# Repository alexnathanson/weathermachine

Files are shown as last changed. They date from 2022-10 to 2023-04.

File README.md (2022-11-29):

# weathermachine

All the code for controlling the system from a centralized computer/ server is in main

To run:

`python main`

To do:

smooth numbers over time (change based on user input - currently hard coded)
light output is an array for some reason...
export test settings?
add gauges
shift to REACT
refactor

Troubleshooting:

If you get a serial error, make sure to close all Arduino windows to ensure that only Python is communicating via Serial

clean data is defined here as data with 1 single row of headers.
it does not necessarily mean there aren't problems in the data

HEADERS:
Date
HH:MM
Datasource
Dry Bulb Temperature {C}
Dew Point Temperature {C}
Relative Humidity {%}
Atmospheric Pressure {Pa}
Extraterrestrial Horizontal Radiation {Wh/m2}
Extraterrestrial Direct Normal Radiation {Wh/m2}
Horizontal Infrared Radiation Intensity from Sky {Wh/m2}
Global Horizontal Radiation {Wh/m2}
Direct Normal Radiation {Wh/m2}
Diffuse Horizontal Radiation {Wh/m2}
Global Horizontal Illuminance {lux}
Direct Normal Illuminance {lux}
Diffuse Horizontal Illuminance {lux}
Zenith Luminance {Cd/m2}
Wind Direction {deg}
Wind Speed {m/s}
Total Sky Cover {.1}
Opaque Sky Cover {.1}
Visibility {km}
Ceiling Height {m}
Present Weather Observation
Present Weather Codes
Precipitable Water {mm}
Aerosol Optical Depth {.001}
Snow Depth {cm}
Days Since Last Snow
Albedo {.01}
Liquid Precipitation Depth {mm}
Liquid Precipitation Quantity {hr}

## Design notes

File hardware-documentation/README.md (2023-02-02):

# Hardware

## LED panel

4 total

https://www.mars-hydro.com/ts-3000-led-grow-light

## LED Power Supply

1 per LED panel

https://www.meanwell.com/webapp/product/search.aspx?prod=ELG-240

## LED Light PWM Driver

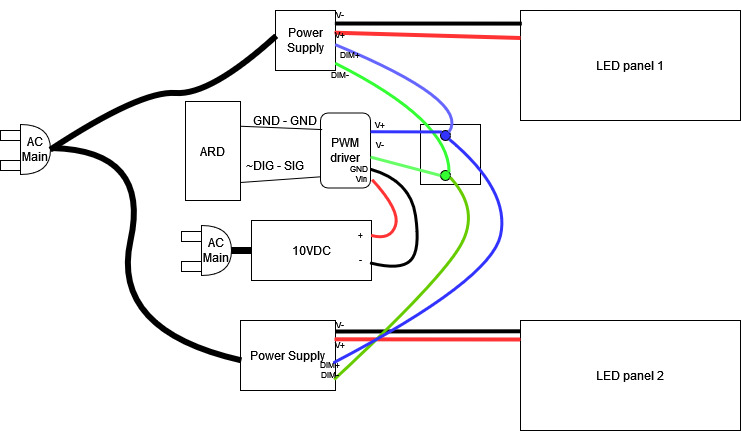
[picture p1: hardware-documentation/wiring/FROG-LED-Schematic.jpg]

IRF520 MOSFET Driver Module

Max:<br>
24VDC<br>
5A (>1A requires heatsink)

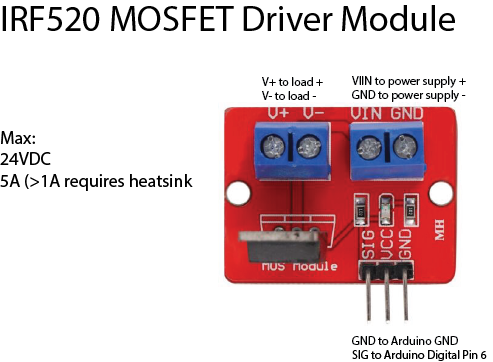
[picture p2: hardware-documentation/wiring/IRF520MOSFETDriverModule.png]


### Purchase Link

* 10VDC Power supply w/ barrel jack breakout https://www.amazon.com/gp/product/B09HT1BB2C/ref=ox_sc_act_title_1?smid=A362H7KPT65UPW&psc=1
* Mosfet driver board:
https://www.amazon.com/dp/B09TFFNH32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

## Pump motor driver

7-30VDC
10A (15A peak)

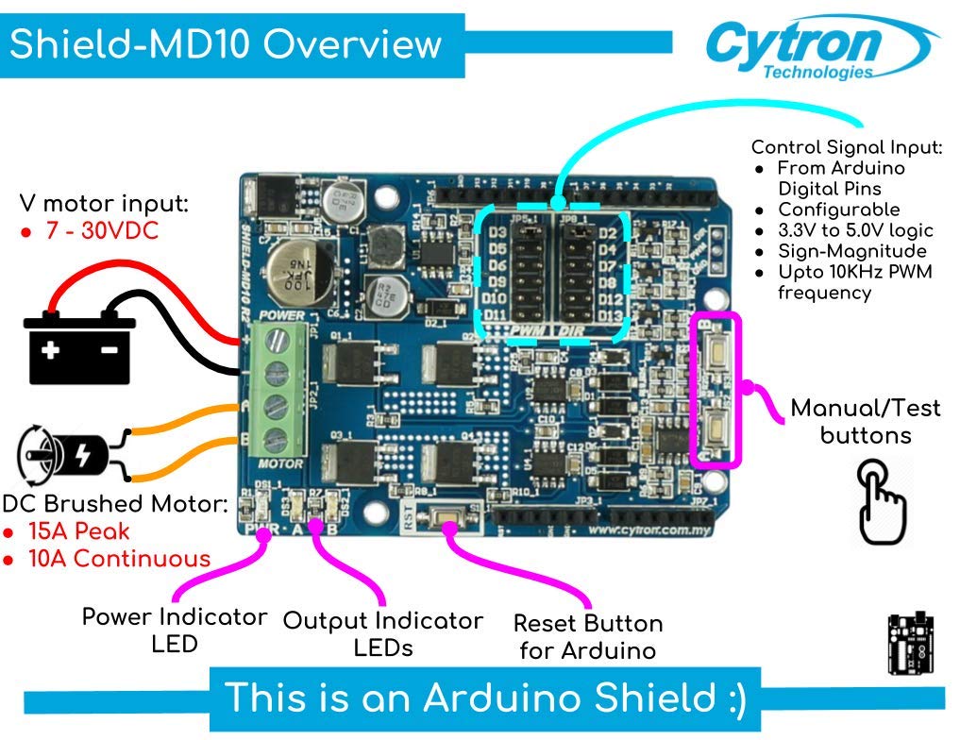
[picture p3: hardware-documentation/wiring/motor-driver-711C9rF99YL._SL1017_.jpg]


### Purchase Link

* https://www.amazon.com/Cytron-Bi-directional-Driver-Shield-Arduino/dp/B01M3WQWRK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

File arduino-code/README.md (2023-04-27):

# Arduino I2C network

This system is composed of 5 Arduinos and a computer that acts as the test runner (TR).

The test runner is a Python program. It sends commands via Serial. 1 Arduino receives this serial data and passes it on to all the other Arduinos that run individual subsystems via I2C. The system is intended to be modular, to enable the system to run with any amount of subsystems connected and so development work can happen more easily.

Some of the individual subsystems have sensors. In some cases these sensors are just used for control feedback to maintain a certain output level, but in some cases sensor data may need to be logged. For this reason, communication in the system is bidirectional. All subsystem Arduinos can pass data back to the TR via sending it over I2C to the broadcaster Arduino, which converts it in to Serial to send to the TR.

The TR determines what commands to send to the subsystems based on user defined test parameters (see the main README.md file for more info). The data originates from an EPW file. In order to simplify comunication and computational load on the Arduinos, the least amount and smallest dimension of data is sent to the Arduinos as possible. Some of subsystem data requires preprocessing that happens on the TR either before the test or on the fly at runtime. In some cases, the Arduino does handle a small amount of preprocessing.

The only piece of code necessary is the serial-to-i2c-bidirectional-subsystem-control.ino script. Change the subsystem variable to the correct number and the Arduino will automatically parse messages and run the correct subsystem. (Currently, the only subsystem code included is for the lights and humidity systems.)

## Installation of serial-to-i2c-bidirectional-subsystem-control.ino

### Software

Make sure to change the I2C address based on the list of subsystem addresses below.

Install Arduino Json https://arduinojson.org/v6/doc/installation/

### Wiring

All Arduinos are connected together via pins GND, A4, and A5. Note that if Arduinos share a power supply with a common ground, the GND pin connection isn't necessary.

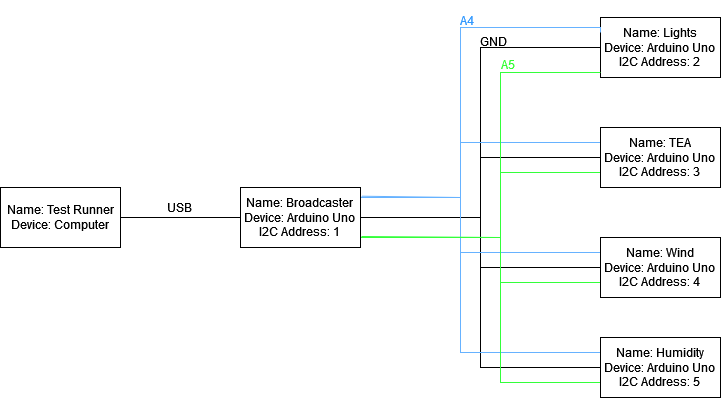
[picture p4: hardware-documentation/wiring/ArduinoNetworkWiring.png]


### Adddresses

 * BROADCASTER : 1
 * LIGHTS : 2
 * TEA : 3
 * WIND : 4
 * HUMIDITY : 5

## Subsystems

### Lights

The lights are controlled via PWM from the Arduino. There are no sensors. Preprocessing of the light data happens at the test runner and only 1 0-255 value is passed to the Arduino.

* Original data sources: Global Horizontal Radiation {Wh/m2}, Diffuse Horizontal Radiation {Wh/m2}, and Direct Normal Radiation {Wh/m2} is reduced down to 1 value based on surface orientation.
* Preprocessing on TS: Surface orientation value is scaled to the 0-255 range.
* Output from TS to Arduino: integer 0-255
* Output from Arduino to light circuit: PWM

### TEA

* Original data sources: Temperature TBD
* Preprocessing on TS: TBD
* Output from TS to Arduino: 1 temperature value
* Output from Arduino to circuit: 2 values (intensity and direction)

### Humidity

* Original data sources: humidity value TBD
* Preprocessing on TS: likely none
* Output from TS to Arduino: 1 value TBD
* Output from Arduino to circuit: TBD wind velocity and temperature

### Wind

* Original data sources: Wind velocity and direction TBD
* Preprocessing on TS: TBD - preprocessing of wind velocity + direction to get 1 value will be required
* Output from TS to Arduino: 1 value TBD
* Output from Arduino to circuit: TBD wind velocity and temperature

## Communication Protocol & Serial String Structure

### From TS to Broadcaster via Serial
The TS sends all data to the Arduino network as a JSON dictionary in the following format. Regardless of what subsystem info is include, all data is broadcast to the entire network. This can be changed in the future if it leads to problems.

`{ lights : [int 0-255]}`

or for multiple values: 

`{ lights : [int 0-255], tea: [int 0-255],hum:[int 0-255],wind:[int 0-255]}`

### Broadcaster On receiving Serial:

1) parse JSON
2) break up JSON data by subsystem
3) broadcast all data to all devices

### Broadcaster on receiving I2C:

1) pass incoming data to Serial

### Subsystems on receiving Serial:

1) send to Broadcaster via 12C

### Subsystems on receiving I2C:

1) parse incoming JSON data
2) check if data is intended for the particular subsystem
3) if yes, run run system functions

### From Arduino to TS

Because exact sensor data that would get sent from subsystems to TS for archiving isn't available yet, that specific format isn't finalized, but it will probably follow a similar JSON format as above, except messages would be seperated out as individual subsystems like the below theoretical example with 3 different temperature sensors. As with communication in the other direction, it is best to reduce the dimension of data if possible. So in this example, unless you need to archive all 3 pieces of data it would be best to just send an average.

`{ tea: {temp1: [int 0-255], temp2: [int 0-255], temp3: [int 0-255]}`

## Troubleshooting

### Network status

In the Arduino IDE console, type "info" and the Arduino will respond with 
* its own I2C address
* a list of all the I2C devices and their addresses that it can detect
* the total number of I2C devices it can detect

In the Arduino IDE console, type "test" and the Arduino will send a properly formatted I2C message with 0 values

### Message Content

In the Arduino IDE, open a console and any incoming messages from I2C should print out as they come in.

## Adding Subsystem Specific Code

## Future Work

It might be best to have 1 library that encompasses all network functions and subsystem functions so that each Arduino can have identical software running.

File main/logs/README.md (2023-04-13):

# Logs

## Naming convention

scriptYEAR-MONTH-DAY-HOUR-MINUTE.log

Log file names starting with 'tester' are run from the arduinoTester script.
Log file names starting with 'runner' are run from the experiment runner script.

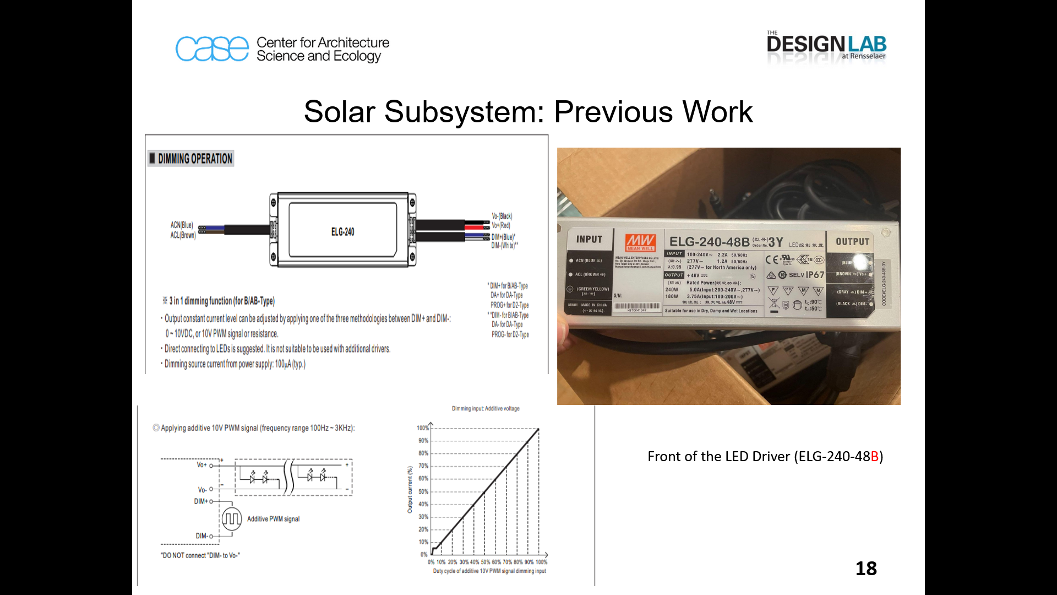
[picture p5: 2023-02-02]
hardware-documentation/Screenshot (737).png

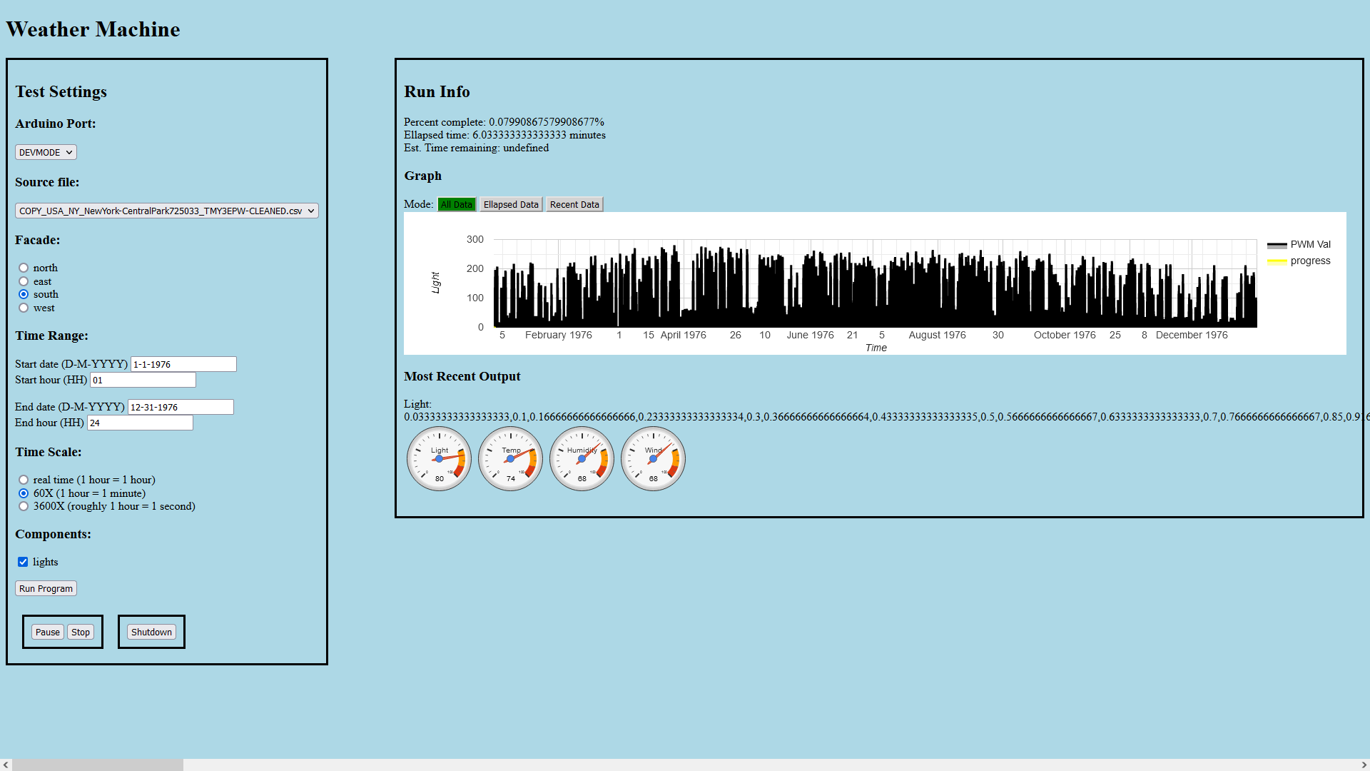
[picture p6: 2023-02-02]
hardware-documentation/interface-screenshot-January30-2023.png

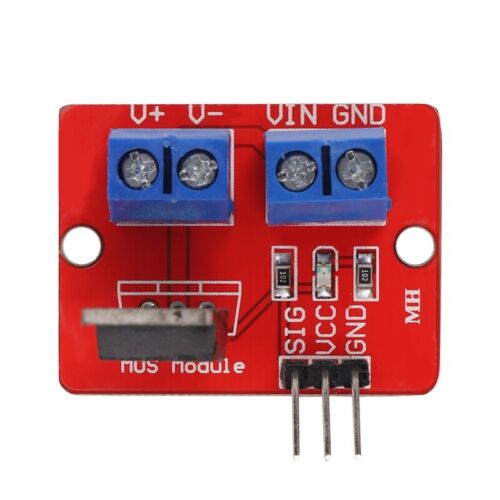
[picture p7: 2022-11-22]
hardware-documentation/IRF520-MOS-PWM.jpg

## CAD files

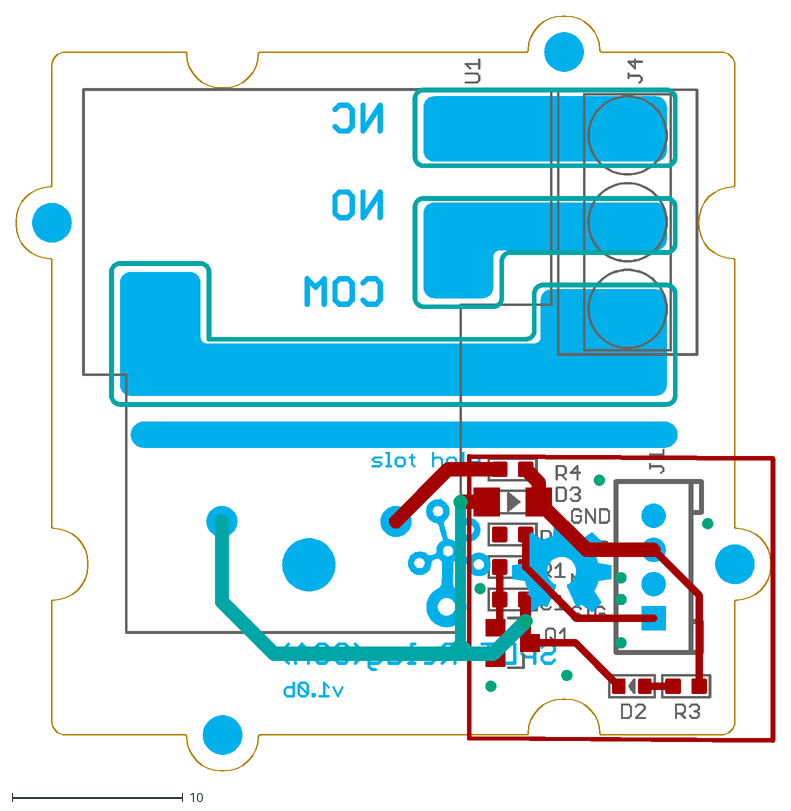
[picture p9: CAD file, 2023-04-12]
integration-and-installation/Grove_-_SPDT_Relay(30A)_Eagle_File/Grove - SPDT Relay(30A) Eagle File/Grove ¿C SPDT Relay(30A) v1.0.dxf
44.5 x 44.2

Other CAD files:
integration-and-installation/ArduinoUno.dxf

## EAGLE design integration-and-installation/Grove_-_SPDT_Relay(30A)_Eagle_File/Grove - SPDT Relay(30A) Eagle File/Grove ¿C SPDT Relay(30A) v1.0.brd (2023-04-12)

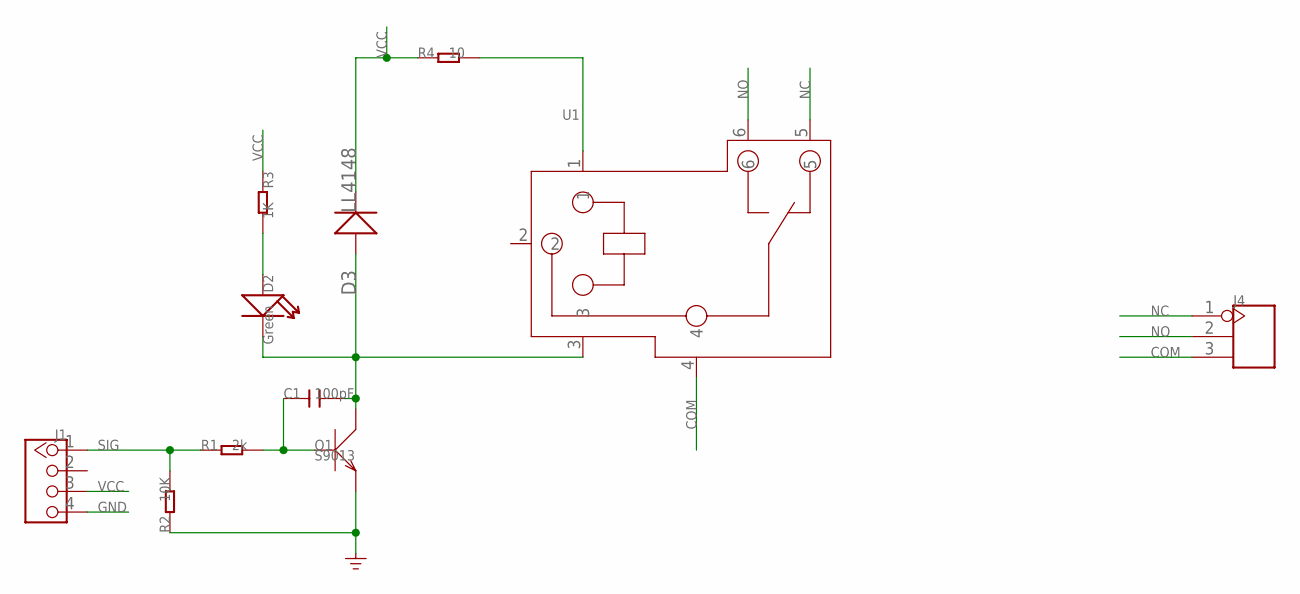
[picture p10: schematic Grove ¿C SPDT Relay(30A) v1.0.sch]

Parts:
C1: 100pF; C0603
D2: Green; LED-0603
D3: LL4148; DO-35-SMD
J1: TWIG-4P-2.0-2.0; 4P-2.0
J4: SCREW-TERMINAL-3P'5.08'; 3P-5.08
Q1: S9013; SOT23
R1: 2k; R0603
R2: 10K; R0603
R3: 1K; R0603
R4: 10; R0603
U1: RELAY-SLA-05VDC-SL-C; 6P-19.8H

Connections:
COM: J4.3, U1.4
GND: J1.4, Q1.2 (E), R2.1
unnamed: C1.1, Q1.1 (B), R1.2
unnamed: D2.+, R3.2
unnamed: C1.2, D2.-, D3.A (+), Q1.3 (C), U1.3
unnamed: R4.2, U1.1
NC: J4.1, U1.5
NO: J4.2, U1.6
SIG: J1.1, R1.1, R2.2
VCC: D3.C (-), J1.3, R3.1, R4.1

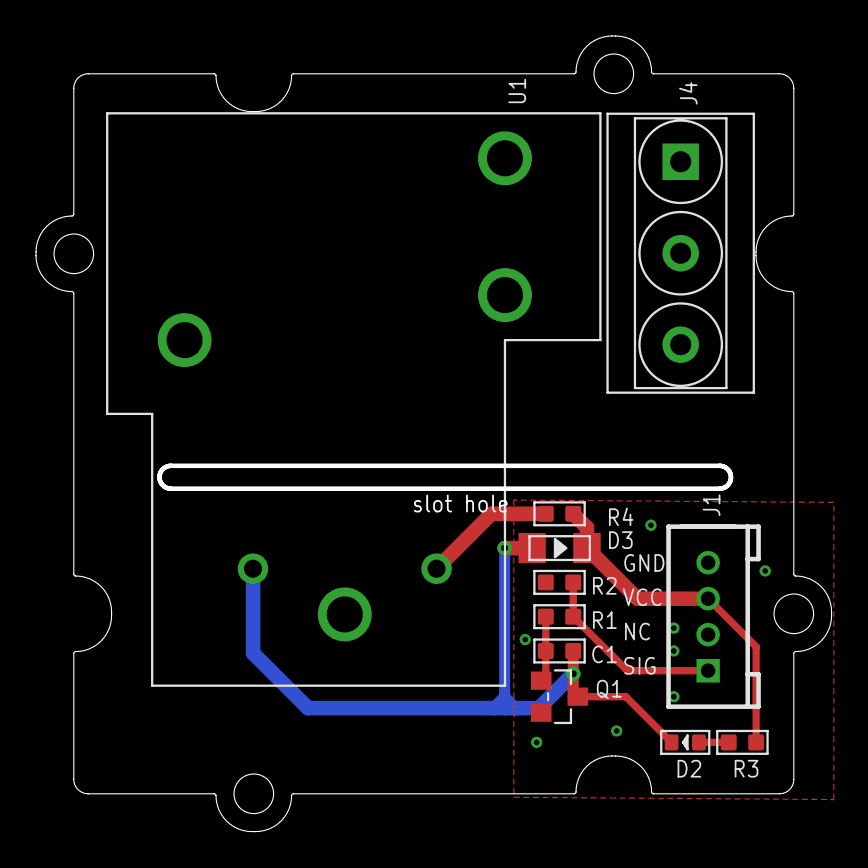
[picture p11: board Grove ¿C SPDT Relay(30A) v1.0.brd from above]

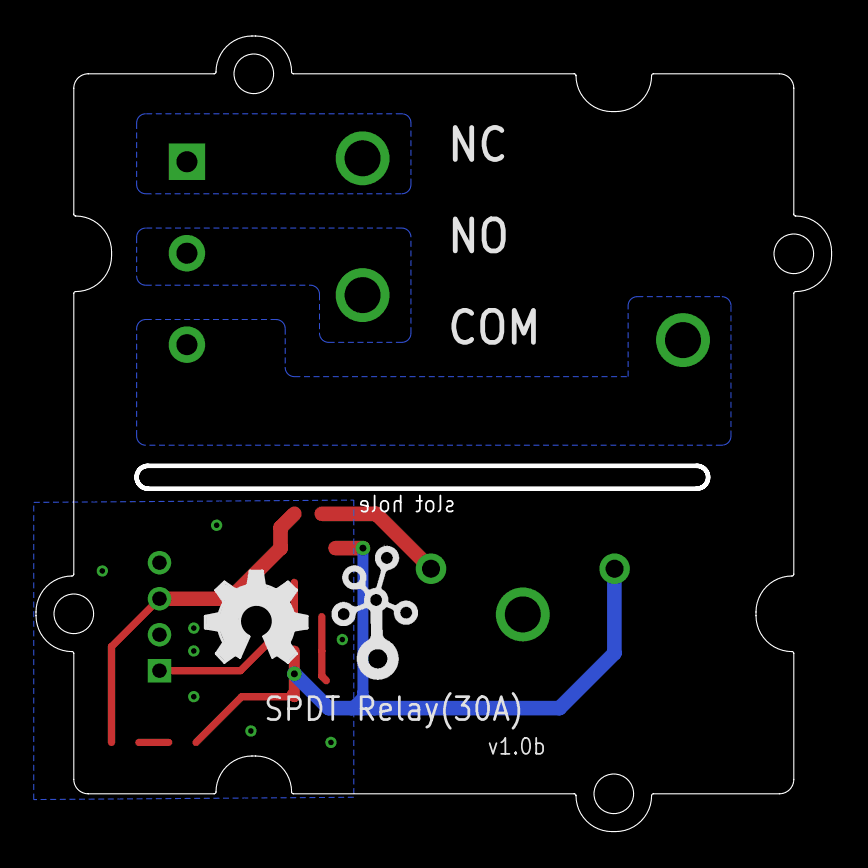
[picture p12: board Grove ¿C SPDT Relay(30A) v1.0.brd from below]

Board: 2 copper layers, 44.2 x 44.2 mm, 14 parts (2 on the bottom side), 10 nets.

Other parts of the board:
U$3: 2X2U-DIM-W/-DRILL
U$4: OSHW_FILLX200_NOTEXT
U$5: TWIGLOGO

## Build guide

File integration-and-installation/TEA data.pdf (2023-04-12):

Arduino | I/O | Analog/digital | Auto/Manual
Temp Sensor 1 | input | analog | Automatic
Temp Sensor 2 | input | analog | Automatic
Temp Sensor 3 | input | analog | Automatic
Temp Sensor 4 | input | analog | Automatic
TEM Power | out | PWM 0-255 mapped to 0-100 | Adjustments should eventually be automatic after manual input of a desired temperature, currently we are setting the power manually
4. A closed feedback loop should be utilized to maximize efficiency of the TEM. The input of the system will be a desired temperature. The controller will likely be a constant gain value that we have not yet determined. This will determine the power of the TEM, or the process. Then, the output of the process will be sent back into the system by the sensors. The error will be calculated, then this will again determine the new power of the system.

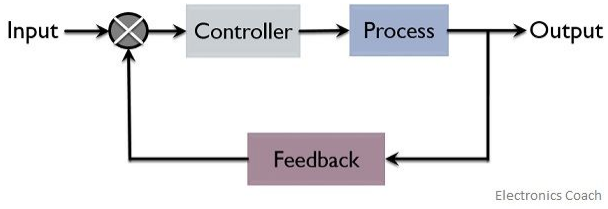
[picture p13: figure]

6. After increasing the desired power of the TEM by 10%, it took about 4 minutes for the temperature to stabilize. This usually results in a temperature increase/decrease of about 1.5 degrees Celsius. So far this is all the testing we have done, more tests will need to be obtained to get more useful and accurate data.

Data sheets

TEA:
https://lairdthermal.com/products/thermoelectric-cooler-assemblies/peltier-air-conditioners/AA-4 80-24-44 (https://lairdthermal.com/products/thermoelectric-cooler-assemblies/peltier-air-conditioners/AA-480-24-44)

H-Bridge:
https://www.pololu.com/product/2994

Power Supply (SE-1000-24): https://www.meanwell.com/productPdf.aspx?i=475

Temperature Sensors:
https://www.te.com/usa-en/product-CAT-HSA0001.html

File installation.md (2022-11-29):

# Installation

## Install Python3

https://www.python.org/downloads/

## Set up virtual environment

Create a virtual environment

https://docs.python.org/3/library/venv.html

## install requirements from requirements.txt

`pip install -r requirements.txt`

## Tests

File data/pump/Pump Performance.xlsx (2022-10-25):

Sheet: 100ft Tubing
Voltage (V) | Current (A) | Power (W) | Flow Rate (LPM)
1.999 | 2.073 | 4.14 | 1.07
2.999 | 3.391 | 10.17 | 1.75
3.999 | 4.225 | 16.90 | 2.33
4.998 | 5.315 | 26.56 | 2.87
5.997 | 6.282 | 37.67 | 3.37
6.997 | 7.183 | 50.26 | 3.75
7.997 | 7.788 | 62.28 | 4.09

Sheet: 200ft Tubing
Voltage (V) | Current (A) | Power (W) | Flow Rate (LPM)
1.999 | 2.598 | 5.19 | 0.83
2.999 | 3.703 | 11.11 | 1.44
3.999 | 4.501 | 18.00 | 1.86
4.998 | 5.551 | 27.74 | 2.22
5.997 | 7.321 | 43.90 | 2.62

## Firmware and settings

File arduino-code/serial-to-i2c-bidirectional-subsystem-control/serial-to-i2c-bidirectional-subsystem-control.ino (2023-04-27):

/*This code manages communications between and control of all subsystems.
 * This is the only Arduino code necessary. Change the subsystem variable to the correct value
 * and it will automatically parse messages and run the correct code for the specified subsystem
 * 
 *For more info see the README at:
 *https://github.com/alexnathanson/weathermachine/tree/main/arduino-code 
 */

/*
 * I2C Addresses:
 * BROADCASTER : 1
 * LIGHTS : 2
 * TEA : 3
 * WIND : 4
 * HUMIDITY : 5
 */

#include <Wire.h>
#include <ArduinoJson.h>

byte i2cDevices[128];
int nDevices = 0;

//value should correlate to i2c addressses listed above
const int subsystem = 5;

/*** LIGHT VARIABLES ***/
const int ledPin = 9;
int ledBrightness = 0;

/*** TEA VARIABLES ***/

/*** WIND VARIABLES ***/

/*** HUMIDITY VARIABLES ****/
float RHValue = 50.0;     // Defining the humidity set point in percentage (This value will be imported from weather file)
float PlusOrMinus = 5.0;  // Defining the lower and upper set point for humidity (This value can be changed as per user...)
                          // (...settings. Below lower set point, humidifier will operate and above upper set point, dehumidifier will operate)
const int VP = A0;                    // Defining the pin for analog input through RH sensor
const int HumPin = 4, DeHumPin = 10;  // Defining the pins for digital output to control humidifier and dehumidifier operation

void setup() {
  //initialize array as all 0
  setupDeviceList();

  // Initialize I2C bus
  Wire.begin(subsystem); 
  Wire.setWireTimeout(3000, false);
  Wire.onReceive(receiveEvent); // register event
  //Wire.onRequest(requestEvent); //register event
  
  Serial.begin(9600); // Initialize serial communication

  /*** HUMIDITY VARIABLES ****/
  if(subsystem == 2){
    //lights
    pinMode(ledPin, OUTPUT);
  } else if(subsystem == 3){
    //TEA
  } else if(subsystem == 4){
    //Wind
  } else if(subsystem == 5){
    //humidity
    pinMode(HumPin, OUTPUT);            // Defining the pin for digital output to control the humidifier operation
    pinMode(DeHumPin, OUTPUT);          // Defining the pin for digital output to control the dehumidifier operation
  }
}

void loop() {
  // Read serial input and send it over I2C
  if (Serial.available()) {
    String message = Serial.readStringUntil('\n'); // Read serial message until newline character

    //respond to the info request with your own info
    if (message == "info"){
      Serial.println("***INFO***");
      Serial.println("My address is " + String(subsystem));
      scannerI2C();
    } else if (message == "test"){//run a test
      
      String testJSON = "{\"lights\":254,\"tea\":3,\"hum\":98,\"wind\":176}";
      parseJSON(testJSON);
      delay(3000);
      testJSON = "{\"lights\":0,\"tea\":0,\"hum\":0,\"wind\":0}";
      parseJSON(testJSON);

    } else {
      //Serial.println(message);

      //if broadcaster, parse serial data and broadcast it
      if(subsystem == 1){
        parseJSON(message);
      } else {
        broadcastI2C(message);//
      }
      
    }
  }
  
  if(subsystem == 2){
    lightLoop();
  } else if(subsystem == 3){
    teaLoop();
  } else if(subsystem == 4){
    windLoop();
  }else if(subsystem == 5){
    humidityLoop();
  }
}

void lightLoop(){
  analogWrite(ledPin, ledBrightness);
}

void teaLoop(){
  
}

void windLoop(){
  
}

/* Code for humidity subsystem*/
void humidityLoop(){
  int val, count = 40;
  float RH, avg = 0.0, volt;
  float MinLim, MaxLim;
  for (int i = 0; i < count; i++){
    val = analogRead(VP);             // Reading the voltage analog input signal (0-5V) from the RH sensor
    volt = val * 5000.0/1023.0;       // Converting the bit value of voltage analog signal to mV 
    RH = -1.92 * pow(10,-9)*pow(volt,3) + 1.44 * pow(10,-5) * pow(volt,2) + 3.4 * pow(10,-3) * volt - 12.4;
                                      // Manufacturer specified equation to convert voltage input in mV to RH in percentage
    avg += RH;                        // Adding all the RH readings to average over a period of 20s
    delay(500);                       // Adding a delay of 0.5s between recording sensor readings
  }
  avg /= count;                       // Obtaining the average RH value for the period of 20s
  if (RHValue - PlusOrMinus < 0)
    MinLim = 0;
  else
    MinLim = RHValue - PlusOrMinus;
                                      // Logic section to set the lower set point for relative humidity
  if (RHValue + PlusOrMinus > 100)
    MaxLim = 100;
  else
    MaxLim = RHValue + PlusOrMinus;
                                      // Logic section to set the lower set point for relative humidity
  if (avg <= MinLim)
    digitalWrite(HumPin, HIGH);       // Digital signal to operate the humidifier through a relay module
  else
    digitalWrite(HumPin, LOW);        // Digital signal to stop the operation of the humidifier through a relay module

  if (avg >= MaxLim)
    digitalWrite(DeHumPin, HIGH);     // Digital signal to operate the dehumidifier by powering the fuse and capacitor in ...
                                      // ... its power module
  else
    digitalWrite(DeHumPin, LOW);      // Digital signal to stop the operation of the dehumidifier by cutting the power to ...
                                      // ... the fuse and capacitor in its power module
}

// function that executes whenever data is received from I2C broadcaster
// this function is registered as an event, see setup()
void receiveEvent(int howMany) {
  String incomingI2C = "";//initialize string
  
  while (1 <= Wire.available()) { // loop through all bytes
    char c = Wire.read(); // receive byte as a character
    incomingI2C += c;
    //Serial.print(c);         // print the character
  }
  

  //if not the broadcaster, parse the data to do something with it
  if(subsystem != 1){
      parseJSON(incomingI2C);
      // if a subsystem, you can use this for troubleshooting in the IDE console
      //Serial.println(incomingI2C);
  } else {
    // if broadcaster, this just passes it on to the test runner
    Serial.println(incomingI2C);
  }
  //int x = Wire.read();    // receive byte as an integer
}

//this is only necessary if the Broadcaster hasn't specified an address and needs to request info
/*void requestEvent() {
  Wire.write("hello "); // respond with message of 6 bytes
}*/

void setLights(int brightness){
  Serial.print("Running Lights: ");
  Serial.println(brightness);
  ledBrightness = brightness;
  
  /*if (brightness == 0){
    digitalWrite(ledPin, LOW);
  } else {
    digitalWrite(ledPin, HIGH);
  }*/
}

void setTea(int temp){
  Serial.print("Running TEA: ");
  Serial.println(temp);
  digitalWrite(ledPin, temp);
}

void setHumidity(float humidity){
  Serial.print("Running Humidity: ");
  Serial.println(humidity);
  digitalWrite(ledPin, humidity);

  RHValue = humidity;     // Defining the humidity set point in percentage converted to float
}

void setWind(int wind){
  Serial.print("Running Wind: ");
  Serial.println(wind);
  digitalWrite(ledPin, wind);
}


void setupDeviceList(){
  for (byte d = 0; d < 128; ++d) {
    i2cDevices[d]=0;  
  }  
}

//scan for all connected i2c devices
void scannerI2C(){
  nDevices = 0;
  
  for (byte address = 1; address < 127; ++address) {
    // The i2c_scanner uses the return value of the Wire.endTransmission
    //to see if a device did acknowledge to the address.
    Wire.beginTransmission(address);
    byte error = Wire.endTransmission();

    if (error == 0) {
      Serial.print("I2C device found at address 0x");
      Serial.println(address, HEX);
      i2cDevices[nDevices]=address;
      nDevices = ++nDevices;
    } else if (error == 4) {
      Serial.print("Unknown error at address 0x");
      Serial.println(address, HEX);
      i2cDevices[nDevices]=0;
    } else {
      i2cDevices[nDevices]=0;
    }
  }
  
  if (nDevices == 0) {
    Serial.println("No I2C devices found\n");
  } else {
    Serial.print(nDevices, DEC);
    Serial.println(" I2C devices found.");

    //print location of devices
    Serial.println('\n');
  }

 }

 //broadcast message to all connected i2c devices
 //there may be a more elegant way to do this with sending to the 0 address
void broadcastI2C(String m){
  //Serial.println(m);
  //if this is not the broadcaster, just send the data to the broadcaster.
      //in the future the input would likely not be from Serial but from the sensors
  if(subsystem != 1){
    Wire.beginTransmission(1);
    Wire.write(m.c_str()); // Send the message as a string
    Wire.endTransmission(); // End I2C transmission
  } else {//if this is the broadcaster, broadcast to all devices in the network
    for (byte address = 2; address < 127; ++address) {
      Wire.beginTransmission(address); // Replace with the I2C address of the receiving Arduino
      Wire.write(m.c_str()); // Send the message as a string
      Wire.endTransmission(); // End I2C transmission
    }        
  } 
 }

 void parseJSON(String m){
  //Serial.println("attempting to parse json");
  DynamicJsonDocument doc(200);
  String json = m;
  
  DeserializationError error = deserializeJson(doc, m);

  // Test if parsing succeeds.
  if (error) {
    //Serial.print(F("deserializeJson() failed: "));
    //Serial.println(error.f_str());
    return;
  }

  // if subsystem is 1, broadcast to everythigng
  // breakup serial into individual subsystem chunks to be small enough to send via i2c
    if(subsystem == 1){
      String lights = doc["lights"];
      if (!doc["lights"].isNull()) {
        broadcastI2C("{\"lights\":" + lights + "}");
      }
    
      String wind = doc["wind"];
      if (!doc["wind"].isNull()) {
        broadcastI2C("{\"wind\":" + wind + "}");
      }
    
      String tea = doc["tea"];
      if (!doc["tea"].isNull()) {
        broadcastI2C("{\"tea\":" + tea + "}");
      }
    
      String hum = doc["hum"];
      if (!doc["hum"].isNull()) {
        broadcastI2C("{\"hum\":" + hum + "}");
      }
    } else if(subsystem == 2){
      //check if data is meant for this particular subsystem
      if (!doc["lights"].isNull()) {
        setLights(doc["lights"]);
      }
    } else if (subsystem == 3){
      if (!doc["tea"].isNull()) {
        setTea(doc["tea"]);
      }
    } else if (subsystem == 4){
      if (!doc["wind"].isNull()) {
        setWind(doc["wind"]);
      }
    } else if (subsystem == 5){
      if (!doc["hum"].isNull()) {
        setHumidity(doc["hum"]);
      }
    }

 }

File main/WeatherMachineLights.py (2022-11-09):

#this code is for the weather machine's lighting elements

import pandas as pd
import math
from datetime import datetime

class WMLights:
	def __init__(self, azimuth):
		self.azimuth = azimuth

	'''
	convert Wh/m2 to Lux
	source: "A conversion guide: solar irradiance and lux illuminance", https://www.extrica.com/article/21667/pdf
	"The analysis and measurement show the irradiance to illuminance conversion factor is
	1 W/m2 equals 116 ± 3 lx for indoor LED based solar simulators and 122 ± 1 lx for outdoor natural sunlight.
	An engineering rule of thumb is 120 lx equals 1 W/m2, or 1 Sun equals 120000 lx."

	Note that a more accurate number could probably be used with a precise understanding of the LED light wavelengths
	'''
	# returns a series
	def energyToLux(self, ser):
		print("energy to lux converion: 1W/m^2 = 120lx")

		dF=ser.to_frame()
		#print(dF.columns[0])

		dF['lux'] = dF[dF.columns[0]] * 120
		#dFLux.columns=['lux']
		#print(dF.columns)

		#print(dF.head())
		#print(dF['lux'].iloc[0:10])
		return dF['lux']

	'''
	roughly convert from horizontal point to a particular vertical face

	rough conversion of light intensity for different azimuths
	east (90) = 75%
	south (180) = 100%
	west (270) = 75%
	north (0) = 10%
	'''
	def roughSurfaceOrientationConversion(self, dFC):

		#azimuth conversation
		if self.azimuth == 0: #north
			azScaler = .1
		elif self.azimuth == 90: #east
			azScaler = .75
		elif self.azimuth == 180: #south
			azScaler = 1.0
		elif self.azimuth == 270: #west
			azScaler = .75
		print("surface conversion scaler: " + str(azScaler))

		convertedColumn = dFC * azScaler

		return convertedColumn

	'''
	detailed conversion from horizontal point to a particular vertical face
	equations from Youngjin Hwang
	https://docs.google.com/document/d/11sM10-iicSdTeooRDKgKW0v6Aa3aOrDD/edit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
	'''
	def detailedSurfaceOrientation(self, dfOr):

		HGloHor = dfOr['Global Horizontal Radiation {Wh/m2}']
		DifHor = dfOr['Diffuse Horizontal Radiation {Wh/m2}']
		HDirNor = dfOr['Direct Normal Radiation {Wh/m2}']

		#δ declination angle
		#date str to time
		#this was used before it was previously turn in to a date...
		#dfOr['Date Format'] = dfOr['Date'].apply(self.strToDateTime)

		#date to day number
		dfOr['Day num'] = dfOr['Date Format'].apply(self.dateToDayNumber)
		dfOr['declination'] = dfOr['Day num'].apply(self.declinationAngle)

		#ω solar hour
		dfOr['HH'] = dfOr['HH:MM'].apply(self.hhmmTohh)
		dfOr['solar hour'] = dfOr['HH'].apply(self.solarHour)
		
		sOmega = dfOr['solar hour']
		sDelta = dfOr['declination']
		print(type(sDelta))

		omSin =dfOr['solar hour'].apply(math.sin)
		omCos = dfOr['solar hour'].apply(math.cos)

		#print(sDelta.head())
		delSin = dfOr['declination'].apply(math.sin)
		delCos = dfOr['declination'].apply(math.cos)

		#ϕ 
		# should this get passed in with azimuth?
		sLat = 41

		if self.azimuth == 0: #north
			sTheta = (delSin * math.cos(sLat) - delCos * math.sin(sLat) * omCos).apply(math.asin) 

			#Therefore, hourly total solar irradiation on the wall is:
			sIr = 0.5*HGloHor*0.2 + 0.5*DifHor + HDirNor* sTheta.apply(math.cos)

		elif self.azimuth == 90: #east
			sTheta = ( - delCos * omSin).apply(math.asin)
			sIr = 0.5*HGloHor*0.2 + 0.5*DifHor + HDirNor*sTheta.apply(math.cos)

		elif self.azimuth == 180: #south

			sTheta = (-delSin * math.cos(sLat) + delCos * math.sin(sLat) * omCos).apply(math.asin)
			sIr = 0.5*HGloHor*0.2 + 0.5*DifHor + HDirNor*sTheta.apply(math.cos)

		elif self.azimuth == 270: #west

			sTheta = (delCos * omSin).apply(math.asin)
			sIr = 0.5*HGloHor*0.2 + 0.5*DifHor + HDirNor*sTheta.apply(math.cos)

		elif self.azimuth == 'roof':
			sTheta = (delSin * math.Sin(sLat) + delCost * math.cos(sLat) * omCos).apply(math.asin)
			sIr = HGloHor + HDirNor*sTheta.apply(math.cos)

		dfOr['surface irradiance'] = sIr

		#print(dfOr.iloc[0:20])

		return dfOr['surface irradiance']

	def detailedSurfaceOrientationConversion(self):
		if self.azimuth == 0: #north
			sTheta = math.asin(math.sin(sDelta) * math.cos(sLat) - math.cos(sDelta) * math.sin(sLat) * math.cos(sOmega)) 

			#Therefore, hourly total solar irradiation on the wall is:
			sIr = 0.5*HGloHor*0.2 + 0.5*DifHor + HDirNor*math.cos(sTheta)

		elif self.azimuth == 90: #east
			sTheta = math.asin ( - math.cos(sDelta) * math.sin(sOmega))
			sIr = 0.5*HGloHor*0.2 + 0.5*DifHor + HDirNor*math.cos(sTheta)

		elif self.azimuth == 180: #south

			sTheta = math.asin(-math.sin(sDelta) * math.cos(sLat) + math.cos(sDelta) * math.sin(sLat) * math.cos(sOmega))
			sIr = 0.5*HGloHor*0.2 + 0.5*DifHor + HDirNor*math.cos(sTheta)

		elif self.azimuth == 270: #west

			sTheta = math.asin(math.cos(sDelta) * math.sin(sOmega))
			sIr = 0.5*HGloHor*0.2 + 0.5*DifHor + HDirNor*math.cos(sTheta)

		# elif self.azimuth == 'roof':
		# 	sTheta = math.asin (sin δ sin ϕ + cos δ cos ϕ cos ω)
		# 	sIr = HGloHor + HDirNor*cos(sTheta)

		return sIr

	def strToDateTime(self,dT):
		return datetime.strptime(dT, '%m/%d/%Y').date()

	#convert hours:minutes to just hours
	def hhmmTohh(self,hhmm):
		return int(hhmm.split(':')[0])

	# δ = -0.4092cos(2π/365*(d+10)), where d is the day of year (such that d= 1 on Jan 1)
	def declinationAngle(self, dayNum):
		return -0.4092 * math.cos(2* math.pi/365*(dayNum+10))

	# ω = π/12*(t-12), where t is the local solar time in hours
	def solarHour(self, sTime):
		return math.pi/12*(sTime-12)

	#convert datetime formmated date to day of the year
	# we could also just divide by 24 but that might mess things up when we ease the middle ranges later
	def dateToDayNumber(self,aDate):
		return aDate.timetuple().tm_yday

	'''
	map data frame value to 0 to 255
	returns a series
	'''
	def convertToArduinoAnalogOutput(self,dFC, ledLuxMax):
		convertedColumn = dFC / ledLuxMax

		convertedColumnA = convertedColumn * 255

		#convertedColumnF = convertedColumnA.clip(lower=0)

		#convert to int
		#convertedColumnF = self.seriesFloor(convertedColumnA)

		#int conversation should probably happen here
		return self.seriesFloor(convertedColumnA)


	# concatinate series of floats to ints
	def seriesFloor(self, aSeries):

		aSeriesL = []

		for i in range(len(aSeries)):
			aSeriesL.append(math.floor(aSeries.iloc[i]))

		aSeriesF = pd.Series(aSeriesL, name=aSeries.name)

		return aSeriesF

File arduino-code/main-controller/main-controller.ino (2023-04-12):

/*
  This code receives serial data from the test runner via Serial (USB) to control weather machine outputs.
  It detects remote devices connected via I2C and passes all incoming serial data to all remote devices
  The remote devices may have sensor data, which they all pass on to this script, which passes it back to the test runner.

  The exact data formats are TBD  
*/

//this is for I2C communication between Arduinos
#include <Wire.h>

int i2cDevices[128];

const int ledPinB = 13; // the pin that the LED is attached to
char sendHello[] = " Hello From Arduino Uno";
char dataConfirmed[] = "Arduino got data";

#define ARRAY_SIZE(array) ((sizeof(array))/(sizeof(int)))

void setup() {
  Wire.begin();
  // initialize serial communication:
  Serial.begin(9600);
  // initialize the LED pin as an output:
  //pinMode(ledPinA, OUTPUT);
  pinMode(ledPinB, OUTPUT);

  Serial.println(sendHello); // sends a \n with text

  scannerI2C();
}

void loop() {
  int brightness;

  // check if data has been sent from the computer:
  if (Serial.available() > 0) {
    // read the most recent byte (which will be from 0 to 255):
    brightness = Serial.parseInt();
    Serial.println(String(brightness)); // sends a \n with text
    // set the brightness of the LED:
    //analogWrite(ledPinA, brightness);
    analogWrite(ledPinB, brightness);

    repeaterI2c(String (brightness));
  }

  delay(10);
}

//repeat all serial messages to all devices connected via I2C
void repeaterI2c(String message){

  //convert String to chars
  char buffer[ARRAY_SIZE(message)];
  
  message.toCharArray(buffer, 32);
  
  for (byte address = 0; address < ARRAY_SIZE(i2cDevices); ++address){
      Wire.beginTransmission(i2cDevices[address]); // transmit to devices
      Wire.write(buffer);        // sends message
      Wire.endTransmission();    // stop transmitting

    }
}

//scan for I2C devices on start up
void scannerI2C(){
  int nDevices = 0;
  Serial.println("Scanning for I2C devices...");

  for (byte address = 1; address < 127; ++address) {
    // The i2c_scanner uses the return value of
    // the Wire.endTransmission to see if
    // a device did acknowledge to the address.
    Wire.beginTransmission(address);
    byte error = Wire.endTransmission();

    if (error == 0) {
      Serial.print("I2C device found at address 0x");
      /*if (address < 16) {
        Serial.print("0");
      }*/
      Serial.print(address, HEX);
      Serial.println(" !");
      i2cDevices[nDevices]=address;
      nDevices = ++nDevices;
    } else if (error == 4) {
      Serial.print("Unknown error at address 0x");
      if (address < 16) {
        Serial.print("0");
      }
      Serial.println(address, HEX);
    }
  }
  
  if (nDevices == 0) {
    Serial.println("No I2C devices found\n");
  } else {
    Serial.print(nDevices, DEC);
    Serial.println(" I2C devices found:");

    //print location of devices
    for (byte address = 0; address < ARRAY_SIZE(i2cDevices); ++address){
      Serial.print(i2cDevices[address], DEC);
      Serial.print(' ');
    }
    Serial.println('\n');
  }
}

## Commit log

2022-09-20 initial work
    [USA_NY_New.York-Central.Park.725033_TMY3EPW.xlsx - USA_NY_New.York-Central.Park.72.csv, USA_NY_NewYork-CentralPark725033_TMY3EPW-CLEANED.csv]
2022-09-20 progress bar
    [USA_NY_NewYork-CentralPark725033_TMY3EPW-CLEANED.csv]
2022-09-27 lux to arduino
2022-10-04 arduino working + lights dataframe
2022-10-25 environment mistake
    [pyvenv.cfg]
2022-10-25 available files for drop down list
    [COPY_USA_NY_NewYork-CentralPark725033_TMY3EPW-CLEANED.csv, Pump Performance.xlsx]
2022-11-22 wiring diagram for MOSFET
2022-11-29 motor driver image
2022-12-06 LED schematic
2023-04-12 serial-to-i2c working
    [ArduinoUno.dxf, Grove ¿C SPDT Relay(30A) v1.0.brd, Grove ¿C SPDT Relay(30A) v1.0.dxf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]
2023-04-13 python tester receiving serial from arduino
2023-04-13 I2C network working properly
2023-04-13 json parcer null 0 fixed
    [arduinoSerial.py, arduinoTester.py, serial-to-i2c-bidirectional.ino]
2023-04-13 cleaned up arduino directory
2023-04-13 arduino schematic
2023-04-13 new wiring diagram
2023-04-18 changed LED to pin 9
2023-04-27 merged humidity code into i2c code
